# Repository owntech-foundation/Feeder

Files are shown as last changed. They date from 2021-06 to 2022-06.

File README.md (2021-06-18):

     * * * * * * * * * * * * * * * * * * * * * * * * * * * *
     *       _                                             *
     *    _ | | _                _______        _          *
     *   / || || \              |__   __|      | |         *
     *  / /`|_| \ \_        ___ __ | | ___  ___| |__       *
     * ( (`  ``  )\ \  /\  / | '_ \| |' _ `/ __| '_ `      *
     *  \ \ ___ / /\ \/  \/ /| |`| | | '__( (__| |`| |     *
     *   \_______/` \__/\__/`|_| |_|_ \___,\___|_| |_|     *
     *    ````````   ``` ```  ``  ```` ```` ``````  ``     *
     * D i g i t a l i z i n g  P o w e r  T o g e t h e r *
     * ``````````````````````````````````````````````````` *
     * * * * * * * * * * * * * * * * * * * * * * * * * * * *

# Low Side Synchronous Buck

This repository contains the design files relative to Low Side
Synchronous Buck Power converter. 

# License 

This project is under CERN-OHL-S open hardware Licence
Licence can be consulted inside of the Licence folder.

# Repository architecture 

The repository has the following organization 

* Datasheet 	Contains all the datasheet of main components and integrated circuits used in the design
* KiCAD_files	Contains the KiCAD project, for this converter two separated .pro files contains the two different pcb that compose the power converter. 
* libs  
   * footprints.pretty Contains the project specific footprints
      * footprints.3Dshapes contains the step files for project specific 3D footprints. 
* License 	Contains the pdf file of the CERN-OHL-S open hardware license
* Logo 		Contains the .png images of the logo used for title block
* Manufacturing_files
   * Definition_Package_Power Contains the definition package for manufacturing
   * Definition_Package_Shield Contains the definition package for manufacturing
* Software	Contains basic software for hardware tests.

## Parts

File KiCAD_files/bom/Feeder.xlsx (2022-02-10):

Prj: | Ultra wide input Feeder |  |  |  | Board Qty: | 100
Co.: |  |  |  |  | Unit Cost: | $0.00
Prj date: | mer. 09 févr. 2022 18:22:15 |  |  |  | Total Cost: | $0.00 |  |  |  | $0.00 | 0 |  |  |  | $0.00 | 0 |  |  |  | $0.00 | 0 |  |  |  | $0.00 | 0 |  |  |  | $0.00 | 0 |  |  |  | $0.00 | 0 |  |  |  | $0.00 | 0 |  |  |  | $0.00 | 0
$ date: | 2022-02-09 18:22:38
Global Part Info |  |  |  |  |  |  | Arrow |  |  |  |  | Digi-Key |  |  |  |  | Farnell |  |  |  |  | LCSC |  |  |  |  | Mouser |  |  |  |  | Newark |  |  |  |  | RS Components |  |  |  |  | TME
Refs | Value | Footprint | Manf# | Qty | Unit$ | Ext$ | Avail | Purch | Unit$ | Ext$ | Cat# | Avail | Purch | Unit$ | Ext$ | Cat# | Avail | Purch | Unit$ | Ext$ | Cat# | Avail | Purch | Unit$ | Ext$ | Cat# | Avail | Purch | Unit$ | Ext$ | Cat# | Avail | Purch | Unit$ | Ext$ | Cat# | Avail | Purch | Unit$ | Ext$ | Cat# | Avail | Purch | Unit$ | Ext$ | Cat#
C6 | 3.3uF, 400V | CP_Elec_10x10 | UUX2G3R3MNL1GS | 100 | $0.000 | $0.00 |  |  |  |  |  | 149 |  | $0.000 | $0.00 | 493-9988-1-ND (https://octopart.com/click/track?ai=8078&sig=0beef3b&sid=459&ppid=28166027&vpid=73754946&ct=offers) |  |  |  |  |  |  |  |  |  |  | 10 |  | $0.000 | $0.00 | 647UUX2G3R3MNL1GS (https://octopart.com/click/track?ai=8078&sig=02f3097&sid=2401&ppid=28166027&vpid=419389874&ct=offers) | NonStk |  | $0.000 | $0.00 | 44X4801 (https://octopart.com/click/track?c=1&ai=8078&sig=0e910e7&sid=2402&ppid=28166027&vpid=120922159&ct=offers) |  |  |  |  |  | NonStk |  | $0.000 | $0.00 | UUX2G3R3MNL1GS (https://octopart.com/click/track?ai=8078&sig=046e6c6&sid=1532&ppid=28166027&vpid=709108499&ct=offers)
C7 | 22nF | C_0805_2012Metric | CL21B223KBANNWC | 100 | $0.000 | $0.00 |  |  |  |  |  | 1 |  | $0.000 | $0.00 | 1276-2489-1-ND (https://octopart.com/click/track?ai=8078&sig=073ca1c&sid=459&ppid=24958179&vpid=72526342&ct=offers) |  |  |  |  |  |  |  |  |  |  | 192855 |  | $0.000 | $0.00 | 187CL21B223KBANNWC (https://octopart.com/click/track?ai=8078&sig=00f3e82&sid=2401&ppid=24958179&vpid=726965811&ct=offers)
C8 | 1nF | C_0805_2012Metric | CL21B102KBANNNC | 100 | $0.000 | $0.00 | 53 |  | $0.000 | $0.00 | CL21B102KBANNNC (https://octopart.com/click/track?ai=8078&sig=06aa4b8&sid=1106&ppid=9299369&vpid=486017912&ct=offers) | 246849 |  | $0.000 | $0.00 | 1276-1020-1-ND (https://octopart.com/click/track?ai=8078&sig=0799db1&sid=459&ppid=9299369&vpid=72525966&ct=offers) | 80000 |  | $0.000 | $0.00 | 3013466 (https://octopart.com/click/track?ai=8078&sig=03081e6&sid=11744&ppid=9299369&vpid=541618916&ct=offers) | 175000 |  | $0.000 | $0.00 | C51210 (https://octopart.com/click/track?ai=8078&sig=01941ba&sid=27971&ppid=9299369&vpid=478449047&ct=offers) | 61331 |  | $0.000 | $0.00 | 187CL21B102KBANNNC (https://octopart.com/click/track?ai=8078&sig=0e237f6&sid=2401&ppid=9299369&vpid=659501522&ct=offers) | 42677 |  | $0.000 | $0.00 | 82AC9409 (https://octopart.com/click/track?ai=8078&sig=00bb4d6&sid=2402&ppid=9299369&vpid=511545733&ct=offers) |  |  |  |  |  | 6300 |  | $0.000 | $0.00 | CL21B102KBANNNC (https://octopart.com/click/track?ai=8078&sig=0f7fd1f&sid=1532&ppid=9299369&vpid=709157390&ct=offers)
C9 | 2.2uF | C_0805_2012Metric | CGA4J3X7R1H225K125AE | 100 | $0.000 | $0.00 | 3 |  | $0.000 | $0.00 | CGA4J3X7R1H225K125AE (https://octopart.com/click/track?ai=8078&sig=04caa6a&sid=1106&ppid=48568697&vpid=473450299&ct=offers) | 186 |  | $0.000 | $0.00 | 445-172477-1-ND (https://octopart.com/click/track?ai=8078&sig=0cbb5a1&sid=459&ppid=48568697&vpid=156791176&ct=offers) | NonStk |  | $0.000 | $0.00 | 2547054 (https://octopart.com/click/track?c=1&ai=8078&sig=0b88586&sid=819&ppid=48568697&vpid=262384550&ct=offers) |  |  |  |  |  | 22112 |  | $0.000 | $0.00 | 810CGA4J3X7R1H225KE (https://octopart.com/click/track?ai=8078&sig=0e6e3df&sid=2401&ppid=48568697&vpid=179719319&ct=offers) | NonStk |  | $0.000 | $0.00 | 84Y5689 (https://octopart.com/click/track?c=1&ai=8078&sig=04670b1&sid=2402&ppid=48568697&vpid=263616676&ct=offers) | 49040 |  | $0.000 | $0.00 | 9155257 (https://octopart.com/click/track?ai=8078&sig=063517c&sid=10022&ppid=48568697&vpid=268634339&ct=offers)
C12 | X7T, 100nF | C_0805_2012Metric | C2012X7T2E104M125AA | 100 | $0.000 | $0.00 | 2011 |  | $0.000 | $0.00 | C2012X7T2E104M125AA (https://octopart.com/click/track?ai=8078&sig=0181695&sid=1106&ppid=28169232&vpid=475688280&ct=offers) | 27982 |  | $0.000 | $0.00 | 445-14563-1-ND (https://octopart.com/click/track?ai=8078&sig=0a0f4e8&sid=459&ppid=28169232&vpid=73766894&ct=offers) | NonStk |  | $0.000 | $0.00 | 2839009 (https://octopart.com/click/track?c=1&ai=8078&sig=0eac3cb&sid=819&ppid=28169232&vpid=489916687&ct=offers) |  |  |  |  |  | 7395 |  | $0.000 | $0.00 | 810C2012X7T2E104MAA (https://octopart.com/click/track?ai=8078&sig=0eae5db&sid=2401&ppid=28169232&vpid=165546343&ct=offers) | NonStk |  | $0.000 | $0.00 | 29X4838 (https://octopart.com/click/track?c=1&ai=8078&sig=0ee07f9&sid=2402&ppid=28169232&vpid=120992231&ct=offers)
C14,C15 | 6.8nF | C_0805_2012Metric | 0805B682K631CT | 200 | $0.000 | $0.00 |  |  |  |  |  | NonStk |  | $0.000 | $0.00 | 1292-0805B682K631CTTR-ND (https://octopart.com/click/track?c=1&ai=8078&sig=01f460f&sid=459&ppid=71780471&vpid=788565294&ct=offers) |  |  |  |  |  |  |  |  |  |  | 470 |  | $0.000 | $0.00 | 7910805B682K631CT (https://octopart.com/click/track?ai=8078&sig=02fc642&sid=2401&ppid=71780471&vpid=536603843&ct=offers)
C16 | 10uF | C_1210_3225Metric | UMK325C7106KM-T | 100 | $0.000 | $0.00 |  |  |  |  |  | NonStk |  | $0.000 | $0.00 | UMK325C7106KM-T-ND (https://octopart.com/click/track?c=1&ai=8078&sig=0264a5d&sid=459&ppid=7073241&vpid=137719881&ct=offers) |  |  |  |  |  |  |  |  |  |  | 181615 |  | $0.000 | $0.00 | 963UMK325C7106KMT (https://octopart.com/click/track?ai=8078&sig=00ab734&sid=2401&ppid=7073241&vpid=87845719&ct=offers) | NonStk |  | $0.000 | $0.00 | 09P7437 (https://octopart.com/click/track?c=1&ai=8078&sig=0140a20&sid=2402&ppid=7073241&vpid=96653055&ct=offers)
C17 | 100uF, 35V | CP_Elec_8x10 | EDH107M035A9MAA | 100 | $0.000 | $0.00 |  |  |  |  |  | NonStk |  | $0.000 | $0.00 | EDH107M035A9MAA-ND (https://octopart.com/click/track?c=1&ai=8078&sig=060caa0&sid=459&ppid=77807158&vpid=409529372&ct=offers) |  |  |  |  |  |  |  |  |  |  | 3550 |  | $0.000 | $0.00 | 80EDH107M035A9MAA (https://octopart.com/click/track?ai=8078&sig=0fc720f&sid=2401&ppid=77807158&vpid=458206257&ct=offers) | NonStk |  | $0.000 | $0.00 | 87AC4813 (https://octopart.com/click/track?c=1&ai=8078&sig=0d1a016&sid=2402&ppid=77807158&vpid=524242692&ct=offers)
C18 | C0G, 100pF | C_0805_2012Metric | CL21C101JBANNNC | 100 | $0.000 | $0.00 | 232000 |  | $0.000 | $0.00 | CL21C101JBANNNC (https://octopart.com/click/track?ai=8078&sig=042812e&sid=1106&ppid=9299371&vpid=486018360&ct=offers) | 50629 |  | $0.000 | $0.00 | 1276-1014-1-ND (https://octopart.com/click/track?ai=8078&sig=03ad40d&sid=459&ppid=9299371&vpid=72526845&ct=offers) | 3950 |  | $0.000 | $0.00 | 3013502 (https://octopart.com/click/track?ai=8078&sig=041580c&sid=819&ppid=9299371&vpid=629188470&ct=offers) | 601250 |  | $0.000 | $0.00 | C1790 (https://octopart.com/click/track?ai=8078&sig=05ecd53&sid=27971&ppid=9299371&vpid=478449053&ct=offers) | 55959 |  | $0.000 | $0.00 | 187CL21C101JBANNNC (https://octopart.com/click/track?ai=8078&sig=0e2e8f4&sid=2401&ppid=9299371&vpid=658751464&ct=offers) | NonStk |  | $0.000 | $0.00 | 82AC9471 (https://octopart.com/click/track?c=1&ai=8078&sig=08c5595&sid=2402&ppid=9299371&vpid=511545797&ct=offers) | 72000 |  | $0.000 | $0.00 | 7665875 (https://octopart.com/click/track?ai=8078&sig=02f6e75&sid=10022&ppid=9299371&vpid=209745986&ct=offers) | 107600 |  | $0.000 | $0.00 | CL21C101JBANNNC (https://octopart.com/click/track?ai=8078&sig=0da7126&sid=1532&ppid=9299371&vpid=709157463&ct=offers)
C19,C20 | 4.7uF | C_1210_3225Metric | DNP | 200 | $0.000 | $0.00
C21 | 680pF | C_1812_4532Metric | 302R29W681KV3E-****-SC | 100 | $0.000 | $0.00 |  |  |  |  |  | 7060 |  | $0.000 | $0.00 | 709-1093-1-ND (https://octopart.com/click/track?ai=8078&sig=078d3bc&sid=459&ppid=7978898&vpid=34203770&ct=offers) |  |  |  |  |  |  |  |  |  |  | 36692 |  | $0.000 | $0.00 | 605302R29W681KV3ESC (https://octopart.com/click/track?ai=8078&sig=094f0bc&sid=2401&ppid=7978898&vpid=81553806&ct=offers) | NonStk |  | $0.000 | $0.00 | 58M3253 (https://octopart.com/click/track?c=1&ai=8078&sig=0621320&sid=2402&ppid=7978898&vpid=12114671&ct=offers)
C22 | 10nF | C_0805_2012Metric | CL21B103KBANNND | 100 | $0.000 | $0.00 |  |  |  |  |  | NonStk |  | $0.000 | $0.00 | CL21B103KBANNND-ND (https://octopart.com/click/track?c=1&ai=8078&sig=07ec1f0&sid=459&ppid=19832252&vpid=72526020&ct=offers) |  |  |  |  |  |  |  |  |  |  | 28655 |  | $0.000 | $0.00 | 187CL21B103KBANNND (https://octopart.com/click/track?ai=8078&sig=099313b&sid=2401&ppid=19832252&vpid=726965796&ct=offers) |  |  |  |  |  |  |  |  |  |  | 10600 |  | $0.000 | $0.00 | CL21B103KBANNND (https://octopart.com/click/track?ai=8078&sig=0718426&sid=1532&ppid=19832252&vpid=709157396&ct=offers)
COMP1,CS1,GND1,GND2,GND3,GND4,MOSD1,MOSG1,MOSS1,TP1,TP6,VIN1,VOUT1,VOUT_GND1 | TestPoint | TestPoint_THTPad_D2.0mm_Drill1.0mm | DNP | 1400 | $0.000 | $0.00
D4 | MURA130T3G | D_SMA | MURA130T3G (https://www.mouser.fr/datasheet/2/308/1/MURA130T3_D-2316423.pdf) | 100 | $0.000 | $0.00 |  |  |  |  |  | NonStk |  | $0.000 | $0.00 | MURA130T3GOSCT-ND (https://octopart.com/click/track?c=1&ai=8078&sig=031c13b&sid=459&ppid=332346&vpid=51297157&ct=offers) | NonStk |  | $0.000 | $0.00 | 1651056 (https://octopart.com/click/track?c=1&ai=8078&sig=0a7f3ce&sid=819&ppid=332346&vpid=139248412&ct=offers) |  |  |  |  |  | 5000 |  | $0.000 | $0.00 | 863MURA130T3G (https://octopart.com/click/track?ai=8078&sig=0333514&sid=2401&ppid=332346&vpid=458432704&ct=offers) | 193 |  | $0.000 | $0.00 | 42K1578 (https://octopart.com/click/track?ai=8078&sig=07a66da&sid=2402&ppid=332346&vpid=2972890&ct=offers)
D5 | 9.1V | D_SOD-323 | MM3Z9V1T1G (https://www.mouser.fr/datasheet/2/308/1/MM3Z2V4T1_D-2316321.pdf) | 100 | $0.000 | $0.00 | 18 |  | $0.000 | $0.00 | MM3Z9V1T1G (https://octopart.com/click/track?ai=8078&sig=0d7b3bb&sid=1106&ppid=700692&vpid=473370526&ct=offers) | 2554 |  | $0.000 | $0.00 | MM3Z9V1T1GOSCT-ND (https://octopart.com/click/track?ai=8078&sig=00c2dd9&sid=459&ppid=700692&vpid=43967584&ct=offers) | 6795 |  | $0.000 | $0.00 | 1150496 (https://octopart.com/click/track?ai=8078&sig=09e01ec&sid=11744&ppid=700692&vpid=210226840&ct=offers) | 3707 |  | $0.000 | $0.00 | C603323 (https://octopart.com/click/track?ai=8078&sig=0c234f1&sid=27971&ppid=700692&vpid=752082712&ct=offers) | 17499 |  | $0.000 | $0.00 | 863MM3Z9V1T1G (https://octopart.com/click/track?ai=8078&sig=0883e79&sid=2401&ppid=700692&vpid=44862044&ct=offers) | 672 |  | $0.000 | $0.00 | 45J1637 (https://octopart.com/click/track?ai=8078&sig=0902ebf&sid=2402&ppid=700692&vpid=2977691&ct=offers) | NonStk |  | $0.000 | $0.00 | 8024653 (https://octopart.com/click/track?c=1&ai=8078&sig=0d07fa4&sid=10022&ppid=700692&vpid=199086310&ct=offers) | NonStk |  | $0.000 | $0.00 | MM3Z9V1T1G (https://octopart.com/click/track?ai=8078&sig=034a10e&sid=1532&ppid=700692&vpid=709121646&ct=offers)
D6 | STTH4R02U | D_SMB | BAS20HT1G | 100 | $0.000 | $0.00 | 1563 |  | $0.000 | $0.00 | BAS20HT1G (https://octopart.com/click/track?ai=8078&sig=038f86c&sid=1106&ppid=709429&vpid=473363759&ct=offers) | 1222 |  | $0.000 | $0.00 | BAS20HT1GOSCT-ND (https://octopart.com/click/track?ai=8078&sig=0e45b77&sid=459&ppid=709429&vpid=34059466&ct=offers) | 8200 |  | $0.000 | $0.00 | 2463444 (https://octopart.com/click/track?ai=8078&sig=0c13577&sid=819&ppid=709429&vpid=255436237&ct=offers) | 10520 |  | $0.000 | $0.00 | C152543 (https://octopart.com/click/track?ai=8078&sig=0ff7a5d&sid=27971&ppid=709429&vpid=476992952&ct=offers) | 15405 |  | $0.000 | $0.00 | 863BAS20HT1G (https://octopart.com/click/track?ai=8078&sig=0fa966a&sid=2401&ppid=709429&vpid=37598335&ct=offers) | 8200 |  | $0.000 | $0.00 | 80Y6660 (https://octopart.com/click/track?ai=8078&sig=02dbe19&sid=2402&ppid=709429&vpid=271850561&ct=offers) | NonStk |  | $0.000 | $0.00 | 7925498P (https://octopart.com/click/track?c=1&ai=8078&sig=0062a5b&sid=10022&ppid=709429&vpid=437535841&ct=offers) | 10 |  | $0.000 | $0.00 | BAS20HT1G (https://octopart.com/click/track?ai=8078&sig=0297028&sid=1532&ppid=709429&vpid=709118471&ct=offers)
D7,D8 | BAS20HT1G | D_SOD-323 | BAS20HT1G | 200 | $0.000 | $0.00 | 1563 |  | $0.000 | $0.00 | BAS20HT1G (https://octopart.com/click/track?ai=8078&sig=038f86c&sid=1106&ppid=709429&vpid=473363759&ct=offers) | 1222 |  | $0.000 | $0.00 | BAS20HT1GOSCT-ND (https://octopart.com/click/track?ai=8078&sig=0e45b77&sid=459&ppid=709429&vpid=34059466&ct=offers) | 8200 |  | $0.000 | $0.00 | 2463444 (https://octopart.com/click/track?ai=8078&sig=0c13577&sid=819&ppid=709429&vpid=255436237&ct=offers) | 10520 |  | $0.000 | $0.00 | C152543 (https://octopart.com/click/track?ai=8078&sig=0ff7a5d&sid=27971&ppid=709429&vpid=476992952&ct=offers) | 15405 |  | $0.000 | $0.00 | 863BAS20HT1G (https://octopart.com/click/track?ai=8078&sig=0fa966a&sid=2401&ppid=709429&vpid=37598335&ct=offers) | 8200 |  | $0.000 | $0.00 | 80Y6660 (https://octopart.com/click/track?ai=8078&sig=02dbe19&sid=2402&ppid=709429&vpid=271850561&ct=offers) | NonStk |  | $0.000 | $0.00 | 7925498P (https://octopart.com/click/track?c=1&ai=8078&sig=0062a5b&sid=10022&ppid=709429&vpid=437535841&ct=offers) | 10 |  | $0.000 | $0.00 | BAS20HT1G (https://octopart.com/click/track?ai=8078&sig=0297028&sid=1532&ppid=709429&vpid=709118471&ct=offers)
J1,J2,J3,J4 | Conn_01x01 | Pad_terminal | DNP | 400 | $0.000 | $0.00
NTC1 | 100k | R_0805_2012Metric | ABNTC-0805-104J-4250F-T (https://www.mouser.fr/datasheet/2/3/ABNTC-0805-253593.pdf) | 100 | $0.000 | $0.00 |  |  |  |  |  | NonStk |  | $0.000 | $0.00 | 535-12856-2-ND (https://octopart.com/click/track?c=1&ai=8078&sig=0d1f3fb&sid=459&ppid=29811146&vpid=194407652&ct=offers) |  |  |  |  |  |  |  |  |  |  | 4044 |  | $0.000 | $0.00 | 815NTC805104J4250FT (https://octopart.com/click/track?ai=8078&sig=090dfaa&sid=2401&ppid=29811146&vpid=430900897&ct=offers) | NonStk |  | $0.000 | $0.00 | 96W7698 (https://octopart.com/click/track?c=1&ai=8078&sig=0b85f5f&sid=2402&ppid=29811146&vpid=95831388&ct=offers)
Q1#1 | TK13P25D,RQ - p1/2 | TO-252-2 | TK13P25D (https://www.mouser.fr/datasheet/2/408/TK13P25D_datasheet_en_20140106-1649876.pdf) | 100 | $0.000 | $0.00
Q1#2 | TK13P25D,RQ - p2/2 | TO-252-2 | RQ (https://www.mouser.fr/datasheet/2/408/TK13P25D_datasheet_en_20140106-1649876.pdf) | 100 | $0.000 | $0.00
R4 | 27k | R_0805_2012Metric | KTR10EZPF2702 | 100 | $0.000 | $0.00 |  |  |  |  |  | 5700 |  | $0.000 | $0.00 | RHM27KAHCT-ND (https://octopart.com/click/track?ai=8078&sig=0782fd9&sid=459&ppid=29236867&vpid=76922610&ct=offers) | 2318 |  | $0.000 | $0.00 | 2919074 (https://octopart.com/click/track?ai=8078&sig=0dab3f0&sid=819&ppid=29236867&vpid=521278501&ct=offers) |  |  |  |  |  | 5470 |  | $0.000 | $0.00 | 755KTR10EZPF2702 (https://octopart.com/click/track?ai=8078&sig=06582ee&sid=2401&ppid=29236867&vpid=447856352&ct=offers) | 2318 |  | $0.000 | $0.00 | 72AC5922 (https://octopart.com/click/track?ai=8078&sig=02426fc&sid=2402&ppid=29236867&vpid=509970016&ct=offers)
R5 | 100k | R_0805_2012Metric | KTR10EZPJ104 | 100 | $0.000 | $0.00 |  |  |  |  |  | NonStk |  | $0.000 | $0.00 | RHM100KBCT-ND (https://octopart.com/click/track?c=1&ai=8078&sig=0b4118a&sid=459&ppid=19170044&vpid=34225415&ct=offers) |  |  |  |  |  |  |  |  |  |  | 15665 |  | $0.000 | $0.00 | 755KTR10EZPJ104 (https://octopart.com/click/track?ai=8078&sig=0a01465&sid=2401&ppid=19170044&vpid=465335302&ct=offers)
R6 | 348K | R_0805_2012Metric | CR0805-FX-3483ELF | 100 | $0.000 | $0.00 |  |  |  |  |  | NonStk |  | $0.000 | $0.00 | CR0805-FX-3483ELF-ND (https://octopart.com/click/track?c=1&ai=8078&sig=0537185&sid=459&ppid=6075373&vpid=63620518&ct=offers) |  |  |  |  |  |  |  |  |  |  | 23062 |  | $0.000 | $0.00 | 652CR0805FX3483ELF (https://octopart.com/click/track?ai=8078&sig=0704b8e&sid=2401&ppid=6075373&vpid=99580320&ct=offers) | NonStk |  | $0.000 | $0.00 | 32K3076 (https://octopart.com/click/track?c=1&ai=8078&sig=0a04ef9&sid=2402&ppid=6075373&vpid=518541576&ct=offers)
R7 | 470 | R_0805_2012Metric | RC0805JR-07470RP | 100 | $0.000 | $0.00 | 4925 |  | $0.000 | $0.00 | RC0805JR07470RP (https://octopart.com/click/track?ai=8078&sig=01aeefa&sid=1106&ppid=47616104&vpid=473551910&ct=offers) | NonStk |  | $0.000 | $0.00 | YAG1333CT-ND (https://octopart.com/click/track?c=1&ai=8078&sig=0e8cd12&sid=459&ppid=47616104&vpid=131496801&ct=offers) |  |  |  |  |  |  |  |  |  |  | 8025 |  | $0.000 | $0.00 | 603RC0805JR07470RP (https://octopart.com/click/track?ai=8078&sig=00ebd60&sid=2401&ppid=47616104&vpid=474033905&ct=offers)
R8 | 348k | R_0805_2012Metric | CR0805-FX-3483ELF | 100 | $0.000 | $0.00 |  |  |  |  |  | NonStk |  | $0.000 | $0.00 | CR0805-FX-3483ELF-ND (https://octopart.com/click/track?c=1&ai=8078&sig=0537185&sid=459&ppid=6075373&vpid=63620518&ct=offers) |  |  |  |  |  |  |  |  |  |  | 23062 |  | $0.000 | $0.00 | 652CR0805FX3483ELF (https://octopart.com/click/track?ai=8078&sig=0704b8e&sid=2401&ppid=6075373&vpid=99580320&ct=offers) | NonStk |  | $0.000 | $0.00 | 32K3076 (https://octopart.com/click/track?c=1&ai=8078&sig=0a04ef9&sid=2402&ppid=6075373&vpid=518541576&ct=offers)
R9 | 240m | R_1210_3225Metric | RCWE1210R240FKEA (https://www.vishay.com/docs/20019/rcwe.pdf) | 100 | $0.000 | $0.00 | 5000 |  | $0.000 | $0.00 | RCWE1210R240FKEA (https://octopart.com/click/track?ai=8078&sig=02fe887&sid=1106&ppid=44349166&vpid=473534196&ct=offers) | 4095 |  | $0.000 | $0.00 | RCWE.24FCT-ND (https://octopart.com/click/track?ai=8078&sig=02c04b0&sid=459&ppid=44349166&vpid=115679007&ct=offers) | 8940 |  | $0.000 | $0.00 | 3784839 (https://octopart.com/click/track?ai=8078&sig=0f94c69&sid=819&ppid=44349166&vpid=751268921&ct=offers) |  |  |  |  |  | 8580 |  | $0.000 | $0.00 | 71RCWE1210R240FKEA (https://octopart.com/click/track?ai=8078&sig=0dc2e7b&sid=2401&ppid=44349166&vpid=117597675&ct=offers) | 1234 |  | $0.000 | $0.00 | 08AJ1694 (https://octopart.com/click/track?ai=8078&sig=0c66e4e&sid=2402&ppid=44349166&vpid=671740672&ct=offers)
R11 | 1.4K | R_0805_2012Metric | RC0805FR-071K4L | 100 | $0.000 | $0.00 | 1832 |  | $0.000 | $0.00 | RC0805FR071K4L (https://octopart.com/click/track?ai=8078&sig=0a345cd&sid=1106&ppid=1180832&vpid=473551161&ct=offers) | 214995 |  | $0.000 | $0.00 | 311-1.40KCRCT-ND (https://octopart.com/click/track?ai=8078&sig=032b5f7&sid=459&ppid=1180832&vpid=1749369&ct=offers) | 13710 |  | $0.000 | $0.00 | 3495993 (https://octopart.com/click/track?ai=8078&sig=0a9328e&sid=819&ppid=1180832&vpid=653863687&ct=offers) |  |  |  |  |  | 22207 |  | $0.000 | $0.00 | 603RC0805FR071K4L (https://octopart.com/click/track?ai=8078&sig=0efb0e9&sid=2401&ppid=1180832&vpid=56304300&ct=offers) | 12880 |  | $0.000 | $0.00 | 82AH8275 (https://octopart.com/click/track?ai=8078&sig=09af2c5&sid=2402&ppid=1180832&vpid=655850498&ct=offers) |  |  |  |  |  | 790 |  | $0.000 | $0.00 | RC0805FR071K4L (https://octopart.com/click/track?ai=8078&sig=00e9036&sid=1532&ppid=1180832&vpid=709258348&ct=offers)
R12,R15,R18 | 10k | R_0805_2012Metric | CRT0805-FZ-1002ELF | 300 | $0.000 | $0.00 | 8275 |  | $0.000 | $0.00 | CRT0805FZ1002ELF (https://octopart.com/click/track?ai=8078&sig=0c026f5&sid=1106&ppid=10484700&vpid=473160273&ct=offers) | 4000 |  | $0.000 | $0.00 | CRT0805-FZ-1002ELFCT-ND (https://octopart.com/click/track?ai=8078&sig=099df1e&sid=459&ppid=10484700&vpid=61158602&ct=offers) | 21 |  | $0.000 | $0.00 | 2008317 (https://octopart.com/click/track?ai=8078&sig=0084ca8&sid=819&ppid=10484700&vpid=138672063&ct=offers) |  |  |  |  |  | 18412 |  | $0.000 | $0.00 | 652CRT0805FZ1002ELF (https://octopart.com/click/track?ai=8078&sig=09f5997&sid=2401&ppid=10484700&vpid=37741697&ct=offers) | 11 |  | $0.000 | $0.00 | 41Y1375 (https://octopart.com/click/track?ai=8078&sig=0f9fbcb&sid=2402&ppid=10484700&vpid=250198205&ct=offers) | 3350 |  | $0.000 | $0.00 | 7409224 (https://octopart.com/click/track?ai=8078&sig=00c13b9&sid=10022&ppid=10484700&vpid=198997719&ct=offers)
R13,R17,R20 | 10 | R_0805_2012Metric | CRCW080510R0JNEAC | 300 | $0.000 | $0.00 | 49 |  | $0.000 | $0.00 | CRCW080510R0JNEAC (https://octopart.com/click/track?ai=8078&sig=0221b64&sid=1106&ppid=23798538&vpid=480974327&ct=offers) | 69322 |  | $0.000 | $0.00 | 541-4167-1-ND (https://octopart.com/click/track?ai=8078&sig=013f719&sid=459&ppid=23798538&vpid=454353720&ct=offers) |  |  |  |  |  |  |  |  |  |  | 138976 |  | $0.000 | $0.00 | 71CRCW080510R0JNEAC (https://octopart.com/click/track?ai=8078&sig=00f8257&sid=2401&ppid=23798538&vpid=458953946&ct=offers) | NonStk |  | $0.000 | $0.00 | 98AC1024 (https://octopart.com/click/track?c=1&ai=8078&sig=0bf89aa&sid=2402&ppid=23798538&vpid=634340864&ct=offers)
R14 | 38.3k | R_0805_2012Metric | CRCW080538K3FKEA | 100 | $0.000 | $0.00 |  |  |  |  |  | 722 |  | $0.000 | $0.00 | 541-38.3KCCT-ND (https://octopart.com/click/track?ai=8078&sig=04292f8&sid=459&ppid=39854820&vpid=114978957&ct=offers) | 9755 |  | $0.000 | $0.00 | 1652988 (https://octopart.com/click/track?ai=8078&sig=06e7e1d&sid=11744&ppid=39854820&vpid=249315642&ct=offers) |  |  |  |  |  | 686 |  | $0.000 | $0.00 | 71CRCW080538.3KE3 (https://octopart.com/click/track?ai=8078&sig=05a8f9c&sid=2401&ppid=39854820&vpid=115160585&ct=offers) | 2610 |  | $0.000 | $0.00 | 53K0193 (https://octopart.com/click/track?ai=8078&sig=0e72440&sid=2402&ppid=39854820&vpid=115416899&ct=offers)
R16 | 2.2 | R_0805_2012Metric | RK73B2ATTDD2R2J | 100 | $0.000 | $0.00 |  |  |  |  |  |  |  |  |  |  |  |  |  |  |  |  |  |  |  |  | 20432 |  | $0.000 | $0.00 | 660RK73B2ATTDD2R2J (https://octopart.com/click/track?ai=8078&sig=0fe4351&sid=2401&ppid=57087488&vpid=193859280&ct=offers)
T1 | PA2467NL | PA2467NL | PA2467NL (https://productfinder.pulseelectronics.com/api/open/product-attachments/datasheet/pa2467nlt) | 100 | $0.000 | $0.00 | 750 |  | $0.000 | $0.00 | PA2467NL (https://octopart.com/click/track?ai=8078&sig=03cddbf&sid=1106&ppid=18290109&vpid=473412033&ct=offers) | NonStk |  | $0.000 | $0.00 | 553-3321-ND (https://octopart.com/click/track?c=1&ai=8078&sig=0015381&sid=459&ppid=18290109&vpid=253365440&ct=offers) |  |  |  |  |  |  |  |  |  |  | 2751 |  | $0.000 | $0.00 | 673PA2467NL (https://octopart.com/click/track?ai=8078&sig=0bea9f7&sid=2401&ppid=18290109&vpid=275699093&ct=offers)
U2 | NCP12700 | MSOP-10_3x3mm_P0.5mm | NCP12700ADNR2G (https://www.onsemi.com/pdf/datasheet/ncp12700-d.pdf) | 100 | $0.000 | $0.00 | 2609 |  | $0.000 | $0.00 | NCP12700ADNR2G (https://octopart.com/click/track?ai=8078&sig=0ba64aa&sid=1106&ppid=89706344&vpid=707207381&ct=offers) | 3797 |  | $0.000 | $0.00 | 1990-NCP12700ADNR2GCT-ND (https://octopart.com/click/track?c=1&ai=8078&sig=009cb1c&sid=459&ppid=89706344&vpid=763727272&ct=offers) | 3969 |  | $0.000 | $0.00 | 2895693 (https://octopart.com/click/track?ai=8078&sig=0a2215c&sid=819&ppid=89706344&vpid=492584107&ct=offers) |  |  |  |  |  | 1355 |  | $0.000 | $0.00 | 863NCP12700ADNR2G (https://octopart.com/click/track?ai=8078&sig=0eba9ca&sid=2401&ppid=89706344&vpid=481500564&ct=offers) | 3969 |  | $0.000 | $0.00 | 62AC7304 (https://octopart.com/click/track?ai=8078&sig=01dd9ed&sid=2402&ppid=89706344&vpid=492708771&ct=offers)
U3 | HMHA2801A | SO-4_4.4x2.3mm_P1.27mm | HMHA2801A (https://www.mouser.fr/datasheet/2/308/1/HMHA2801B_D-2314371.pdf) | 100 | $0.000 | $0.00 |  |  |  |  |  | NonStk |  | $0.000 | $0.00 | HMHA2801A-ND (https://octopart.com/click/track?c=1&ai=8078&sig=078b50c&sid=459&ppid=84329105&vpid=452468346&ct=offers) | 2957 |  | $0.000 | $0.00 | 2453212 (https://octopart.com/click/track?ai=8078&sig=0a90ccc&sid=819&ppid=84329105&vpid=440254787&ct=offers) |  |  |  |  |  | 462 |  | $0.000 | $0.00 | 512HMHA2801A (https://octopart.com/click/track?ai=8078&sig=01f73a8&sid=2401&ppid=84329105&vpid=438584723&ct=offers) | 2158 |  | $0.000 | $0.00 | 31Y2002 (https://octopart.com/click/track?ai=8078&sig=0d5bd16&sid=2402&ppid=84329105&vpid=439870991&ct=offers) |  |  |  |  |  | 3 |  | $0.000 | $0.00 | HMHA2801A (https://octopart.com/click/track?ai=8078&sig=0462abe&sid=1532&ppid=84329105&vpid=763734031&ct=offers)
U4#1 | TL431MFDT,215 - p1/2 | SOT-23 | TL431MFDT (https://www.mouser.fr/datasheet/2/916/TL431_FAM-1600378.pdf) | 100 | $0.000 | $0.00 |  |  |  |  |  |  |  |  |  |  | NonStk |  | $0.000 | $0.00 | 2095481 (https://octopart.com/click/track?c=1&ai=8078&sig=0b0ff44&sid=819&ppid=79112777&vpid=414866965&ct=offers)
U4#2 | TL431MFDT,215 - p2/2 | SOT-23 | 215 (https://www.mouser.fr/datasheet/2/916/TL431_FAM-1600378.pdf) | 100 | $0.000 | $0.00 |  |  |  |  |  | 58 |  | $0.000 | $0.00 | 215PV-ND (https://octopart.com/click/track?ai=8078&sig=0797dd1&sid=459&ppid=89173600&vpid=462080608&ct=offers) | 2 |  | $0.000 | $0.00 | 2903716 (https://octopart.com/click/track?ai=8078&sig=004342a&sid=819&ppid=89173600&vpid=490808707&ct=offers) |  |  |  |  |  |  |  |  |  |  | 2 |  | $0.000 | $0.00 | 62AC1312 (https://octopart.com/click/track?ai=8078&sig=0daa01e&sid=2402&ppid=89173600&vpid=492148436&ct=offers)
 | Used currency rates: |  |  |  | Total Purchase: | $0.00 | Buy here (https://www.arrow.com/en/bom-tool/) |  |  | $0.00 |  | Buy here (https://www.digikey.com/ordering/shoppingcart) |  |  | $0.00 |  | Buy here (https://fr.farnell.com/en-FR/quick-order?isQuickPaste=true) |  |  | $0.00 |  | Buy here (https://lcsc.com/bom.html) |  |  | $0.00 |  | Buy here (https://mouser.com/bom/) |  |  | $0.00 |  | Buy here (https://www.newark.com/quick-order?isQuickPaste=true) |  |  | $0.00 |  | Buy here (https://uk.rs-online.com/web/mylists/manualQuotes.html?method=showEnquiryCreationPage&mode=new) |  |  | $0.00 |  | Buy here (https://www.tme.eu/en/Profile/QuickBuy/load.html) |  |  | $0.00
 | USD($)/GBP(£): | 1.357189484 |  |  | Purchase description: |  |  |  |  |  |  |  |  |  |  |  |  |  |  |  |  |  | Copy this header and order to a CSV file and use it for JLCPCB manufacturer PCB house. The multipart components that use "#" symbol are not allowed by JLCPCB.
KiCost® v1.1.5

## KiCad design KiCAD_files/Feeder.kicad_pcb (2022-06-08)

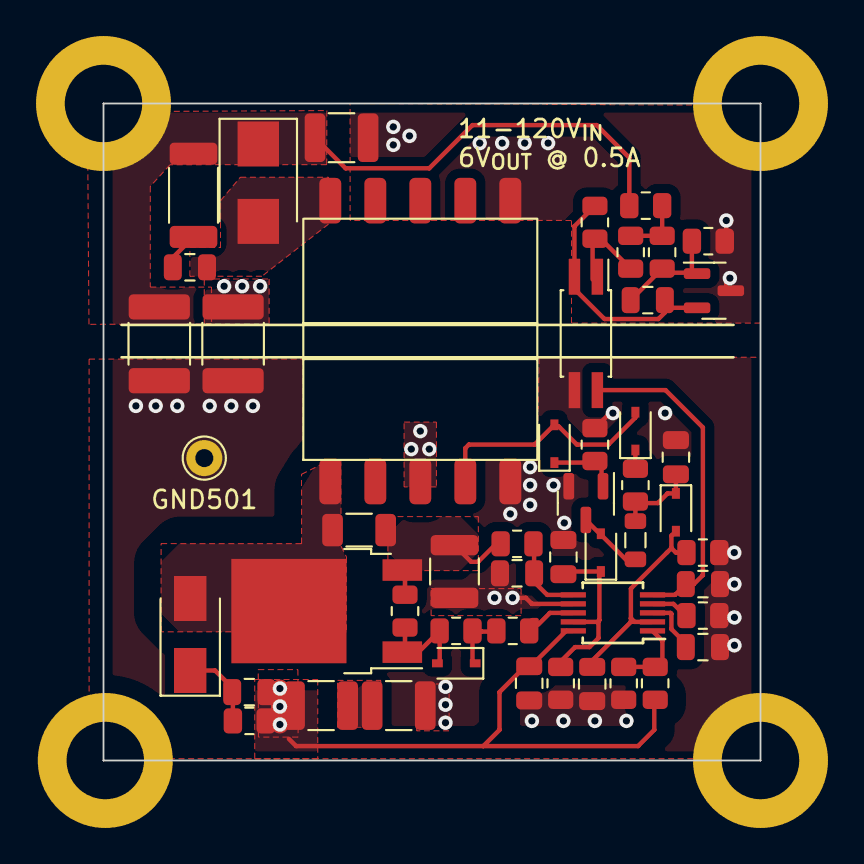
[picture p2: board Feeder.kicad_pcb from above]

Board: 4 copper layers, 36.5 x 36.5 mm, 54 parts (0 on the bottom side), 29 nets.

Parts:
C501, C502: 4.7uF; C_1210_3225Metric
C503: 10nF; C_0805_2012Metric
C504: 22nF; C_0805_2012Metric
C505: 1nF; C_0805_2012Metric
C506: C0G, 100pF; C_0805_2012Metric
C507, C509: 1uF; C_0805_2012Metric
C508: X7T, 100nF; C_0805_2012Metric
C510, C516: 6.8nF; C_0805_2012Metric
C511: 100pF 1kV DNP; C_1206_3216Metric
C512, C513: 2.2nF; C_1812_4532Metric
C514: 1nF 500V DNP; C_0805_2012Metric
C515: 10uF; C_1210_3225Metric
D501: 6.2V; D_SOD-323
D502, D503, D505, D506: BAS20HT1G; D_SOD-323
D504: MURA130T3G; D_SMA
D507: STTH4R02U; D_SMB
GND501: GND; TestPoint_THTPad_D2.0mm_Drill1.0mm
J501, J502, J503, J504: Conn_01x01; MountingHole_4.3mm_M4_DIN965_Pad
L501: 100uH; L_0805_2012Metric
NTC501: 100k; R_0805_2012Metric
Q501: 60V N channel; SOT-23
Q502: TK13P25D,RQ; TO-252-2
R501: 348K; R_0805_2012Metric
R502, R518: 27k; R_0805_2012Metric
R503: 100k; R_0805_2012Metric
R504, R512, R514: 1.4K; R_0805_2012Metric
R505: 2.2; R_0805_2012Metric
R506: 470; R_0805_2012Metric
R507, R511, R516: 10; R_0805_2012Metric
R508, R515: 10k; R_0805_2012Metric
R509: 348k; R_0805_2012Metric
R510: 240m; R_1210_3225Metric
R513: 10R 1W DNP; R_2010_5025Metric
R517: 38.3k; R_0805_2012Metric
T501: PA2467NL
U501: NCP12700; MSOP-10_3x3mm_P0.5mm
U502: HMHA2801A; SO-4_4.4x2.3mm_P1.27mm
U503: TL431MFDT,215; SOT-23

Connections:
/VIN: C501.1, C508.1, C510.1, J501.1, R501.1, R509.2, T501.3, U501.10 (VIN)
/VOUT: C513.2, C515.1, D507.1 (K), J503.1, R513.2, R516.1
DGND: C512.2, C515.2, J504.1, R518.2, T501.10, U503.3 (A)
GND: C502.2, C503.1, C504.2, C505.2, C506.2, C507.2, C508.2, C509.2, C512.1, C513.1, GND501.1, J502.1, NTC501.2, Q501.2 (S), R502.2, R503.2, R504.2, R510.2, R512.2, T501.1, U501.7 (GND), U502.3
HV: C501.2, C502.1
MOSD: C511.1, D504.2 (A), Q502.2 (D), T501.5
MOSS: C511.2, Q502.3 (S), R506.2, R508.1, R510.1
unnamed: C503.2, D501.2 (A), NTC501.1, U501.2 (FLT)
unnamed: C504.1, U501.3 (SS)
unnamed: C505.1, U501.5 (COMP), U502.4
unnamed: C506.1, R506.1, U501.6 (CS)
unnamed: C510.2, D504.1 (K), R509.1
unnamed: C514.1, D507.2 (A), T501.6
unnamed: C514.2, R513.1
unnamed: C516.1, R515.2, U502.2, U503.2 (K)
unnamed: C516.2, R517.2, R518.1, U503.1 (REF)
unnamed: D502.2 (A), L501.1, Q501.3 (D)
unnamed: D503.1 (K), R505.2, R507.1
unnamed: D503.2 (A), Q502.1 (G), R507.2, R508.2
unnamed: D505.1 (K), R511.2
unnamed: D505.2 (A), D506.2 (A), T501.2
unnamed: D506.1 (K), Q501.1 (G), R512.1
unnamed: R501.2, R502.1, U501.1 (UVLO)
unnamed: R503.1, U501.4 (RT)
unnamed: R505.1, U501.8 (DRV)
unnamed: R514.1, R516.2, R517.1
unnamed: R514.2, R515.1, U502.1
VAUX: C509.1, D501.1 (K), L501.2, R511.1
VBoost: C507.1, D502.1 (K), R504.1, U501.9 (VCC)

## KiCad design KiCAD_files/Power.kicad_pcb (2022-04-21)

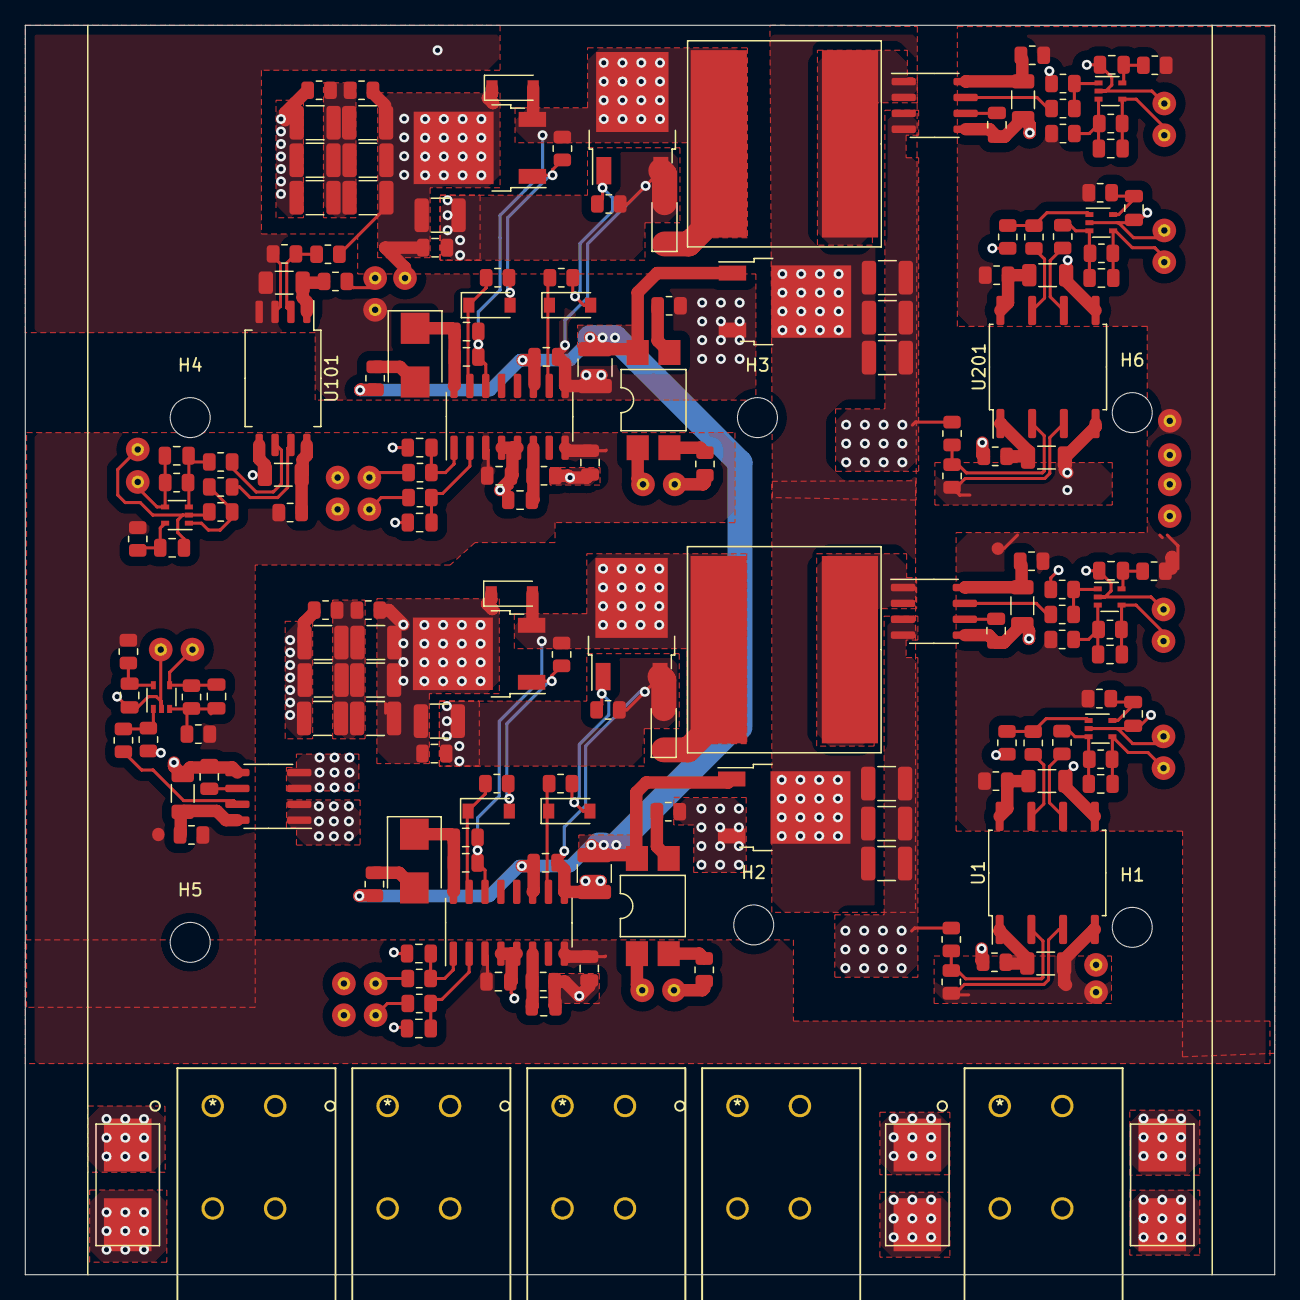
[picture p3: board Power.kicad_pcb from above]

Board: 4 copper layers, 100.0 x 100.0 mm, 215 parts (0 on the bottom side), 97 nets.

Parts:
C1, C11, C12, C101, C102, C120, C201, C211, C212: 100nF; C_1206_3216Metric
C2, C4, C10, C14, C15, C17, C20, C21, C104, C119, C202, C204, C210, C214, C215, C217, C220, C221: 100nF; C_0805_2012Metric
C3, C5, C8, C105, C106, C107, C108, C109, C110, C111, C112, C113, C114, C115, C116, C203, C205, C208: 4.7uF; C_1210_3225Metric
C6, C7, C206, C207: 33pF; C_0805_2012Metric
C9, C118, C209: 1nF; C_0805_2012Metric
C13, C19, C103, C117, C213, C219: 20pF; C_0805_2012Metric
C16, C216: 10uF; C_1210_3225Metric
C18, C218: 1uF; C_0805_2012Metric
C23, C223: 100nF; C_1210_3225Metric
D1, D201: STTH4R02U; D_SMB
D2, D3, D202, D203: STPS0520Z; D_SOD-123
D_L1, D_L3, D_L201, D_L202: STTH1002CB; D_SOD-123
F101, F102, F103: 8A; Fuse_holder_omni_blok
H1, H2, H3, H4, H5, H6: MountingHole; MountingHole_3.2mm_M3
HS101: Heatsink_Pad; custom_heatsink
J1, J2, J3, J4, J5, J6, J7, J8, J9, J10, J104, J105, J106, J107, J108, J109, J110, J111, J112, J113, J114, J115, J116, J201, J202, J203, J204, J205, J206, J207, J208, J209, J210: Conn_01x01; 0906_millmax
J101, J102, J103, J117, J118: 2604-1102; WAGO-2604-1102
L1, L201: 33uH; SRP1510CA-330M
Q1, Q2, Q3, Q201, Q202, Q203: IPD200N15N3; TO-252-2
R1, R2, R19, R201, R202, R219: 51; R_0805_2012Metric
R3, R17, R18, R107, R108, R203, R217, R218: 20k; R_0805_2012Metric
R4, R5, R101, R102, R204, R205: 27k; R_0805_2012Metric
R6, R8, R103, R104, R206, R208: 12k; R_0805_2012Metric
R7, R207: 2.2; R_0805_2012Metric
R9, R14, R15, R21, R22, R23, R24, R25, R26, R27, R28, R29, R30, R31, R105, R110, R209, R214, R215, R221, R222: 1k; R_0805_2012Metric
R10, R11, R210, R211: 2,2; R_0805_2012Metric
R16, R20, R106, R109, R216, R220: 5.9k; R_0805_2012Metric
Rbleed1, Rbleed2, Rbleed101, Rbleed102: 1M; R_0805_2012Metric
Rv1, Rv201: 150K; R_0805_2012Metric
Rv2, Rv202: 470; R_0805_2012Metric
Rv101: 330K; R_0805_2012Metric
Rv102: 5.6K; R_0805_2012Metric
U1, U201: AMC1100DUB; SOP-8_6.62x9.15mm_P2.54mm
U2, U202: ACS730xLCTR-20AB; SOIC-8_3.9x4.9mm_P1.27mm
U3, U203: UCC21222DR; SOIC-16_3.9x9.9mm_P1.27mm
U4, U5, U102, U103, U204, U205: OPA316; SOT-353_SC-70-5
U6, U206: SFH617A-2X009T; SMDIP-4_W7.62mm
U101: AMC1311; SOIC-8_7.5x5.85mm_P1.27mm
U104: +-20A; SOIC-8_3.9x4.9mm_P1.27mm

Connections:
+5P: J104.1, R29.1
+5V: J109.1, R30.1, R31.1
+5VD: C2.1, C4.1, C202.1, C204.1, J107.1, R9.1, R17.1, R21.1, R23.1, R24.1, R25.1, R26.2, R27.1, R28.2, R105.1, R107.1, R110.1, R209.1, R217.1, R221.1, U3.3 (VCCI), U3.8 (VCCI), U203.3 (VCCI), U203.8 (VCCI)
+12V: C14.1, C16.1, C214.1, C216.1, Q3.1 (G), Q203.1 (G), R7.2, R207.2, U3.11 (VDDB), U6.4, U203.11 (VDDB), U206.4
/IIHigh: R106.1, U104.7 (VIOUT)
/IIHigh_op: C117.2, J115.1, R109.2, U103.4
/Power Leg 1/HRTIM1_CH1: J201.1, R201.1
/Power Leg 1/HRTIM1_CH2: J202.1, R202.1
/Power Leg 1/IILow: R216.1, U202.7 (VIOUT)
/Power Leg 1/IILow1_op: C219.2, J209.1, R220.2, U205.4
/Power Leg 1/N_GND: J207.1, U206.1
/Power Leg 1/PWM_H1: D202.1 (K), R210.1, U203.15 (OUTA)
/Power Leg 1/PWM_L1: D203.1 (K), R211.1, U203.10 (OUTB)
/Power Leg 1/SW_Node: C215.2, C218.2, D_L201.1 (K), D_L202.2 (A), L201.2, Q201.3 (S), Q202.2 (D), R214.1, U203.14 (VSSA)
/Power Leg 1/VILow+: Rv201.2, Rv202.1, U201.2 (VINP)
/Power Leg 1/VILow_op: C213.2, J205.1, R208.2, U204.4
/Power Leg 2/HRTIM1_CH1: J1.1, R1.1
/Power Leg 2/HRTIM1_CH2: J2.1, R2.1
/Power Leg 2/IILow: R16.1, U2.7 (VIOUT)
/Power Leg 2/IILow1_op: C19.2, J9.1, R20.2, U5.4
/Power Leg 2/N_GND: J7.1, U6.1
/Power Leg 2/PWM_H1: D2.1 (K), R10.1, U3.15 (OUTA)
/Power Leg 2/PWM_L1: D3.1 (K), R11.1, U3.10 (OUTB)
/Power Leg 2/SW_Node: C15.2, C18.2, D_L1.1 (K), D_L3.2 (A), L1.2, Q1.3 (S), Q2.2 (D), R14.1, U3.14 (VSSA)
/Power Leg 2/VILow+: Rv1.2, Rv2.1, U1.2 (VINP)
/Power Leg 2/VILow_op: C13.2, J5.1, R8.2, U4.4
/V1_Low: C203.1, C205.1, C208.1, F102.1, Rv201.1, U202.3 (IP-), U202.4 (IP-)
/V2_Low: C3.1, C5.1, C8.1, F101.1, Rv1.1, U2.3 (IP-), U2.4 (IP-)
/VIHigh+: Rv101.2, Rv102.1, U101.2 (VIN)
/VIHigh_op: C103.2, J111.1, R104.2, U102.4
/VI_High: F103.1, J118.1, J118.2, J118.3, J118.4
/V_High: C21.1, C23.1, C105.1, C107.1, C109.1, C111.1, C113.1, C115.1, C221.1, C223.1, D_L3.1 (K), D_L202.1 (K), J113.1, Q1.2 (D), Q201.2 (D), Rbleed1.1, Rbleed101.1, Rv101.1, U104.3 (IP-), U104.4 (IP-)
DGND: C2.2, C4.2, C6.1, C7.2, C9.1, C10.2, C11.2, C12.1, C17.2, C20.2, C102.2, C104.2, C118.1, C119.2, C120.1, C202.2, C204.2, C206.1, C207.2, C209.1, C210.2, C211.2, C212.1, C217.2, C220.2, J3.1, J4.1, J6.1, J8.1, J10.1, J106.1, J108.1, J112.1, J116.1, J203.1, J204.1, J206.1, J208.1, J210.1, R3.1, R18.2, R19.1, R103.1, R108.2, R203.1, R218.2, R219.1, U1.5 (GND2), U2.5 (GND), U3.4 (GND), U3.5 (DIS), U4.2 (V-), U5.2 (V-), U101.5 (GND2), U102.2 (V-), U103.2 (V-), U104.5 (GND), U201.5 (GND2), U202.5 (GND), U203.4 (GND), U203.5 (DIS), U204.2 (V-), U205.2 (V-)
GNDREF: C14.2, C16.2, C21.2, C23.2, C101.2, C106.2, C108.2, C110.2, C112.2, C114.2, C116.2, C214.2, C216.2, C221.2, C223.2, D_L1.2 (A), D_L201.2 (A), J114.1, J117.1, J117.2, J117.3, J117.4, Q2.3 (S), Q3.3 (S), Q202.3 (S), Q203.3 (S), R15.1, R22.1, R215.1, R222.1, Rbleed2.2, Rbleed102.2, Rv102.2, U3.9 (VSSB), U101.3 (SHTDN), U101.4 (GND1), U203.9 (VSSB)
NGND: C1.2, C3.2, C5.2, C8.2, C201.2, C203.2, C205.2, C208.2, J103.1, J103.2, J103.3, J103.4, J110.1, Q3.2 (D), Q203.2 (D), Rv2.2, Rv202.2, U1.3 (VINN), U1.4 (GND1), U201.3 (VINN), U201.4 (GND1)
unnamed: C1.1, R31.2, U1.1 (VDD1)
unnamed: C6.2, R1.2, U3.1 (INA)
unnamed: C7.1, R2.2, U3.2 (INB)
unnamed: C9.2, U2.6 (VZCR)
unnamed: C10.1, R3.2, U3.6 (DT)
unnamed: C11.1, R27.2, U1.8 (VDD2)
unnamed: C12.2, R28.1, U2.8 (VCC)
unnamed: C13.1, R5.2, R8.1, U4.3 (-)
unnamed: C15.1, C18.1, D1.1 (K), U3.16 (VDDA)
unnamed: C17.1, R9.2, U4.5 (V+)
unnamed: C19.1, R17.2, R20.1, U5.3 (-)
unnamed: C20.1, R21.2, U5.5 (V+)
unnamed: C101.1, R29.2, U101.1 (VDD1)
unnamed: C102.1, R23.2, U101.8 (VDD2)
unnamed: C103.1, R102.2, R104.1, U102.3 (-)
unnamed: C104.1, R105.2, U102.5 (V+)
unnamed: C105.2, C106.1, C107.2, C108.1, C109.2, C110.1, Rbleed1.2, Rbleed2.1
unnamed: C111.2, C112.1, C113.2, C114.1, C115.2, C116.1, Rbleed101.2, Rbleed102.1
unnamed: C117.1, R107.2, R109.1, U103.3 (-)
unnamed: C118.2, U104.6 (BW_SEL)
unnamed: C119.1, R110.2, U103.5 (V+)
unnamed: C120.2, R24.2, U104.8 (VCC)
unnamed: C201.1, R30.2, U201.1 (VDD1)
unnamed: C206.2, R201.2, U203.1 (INA)
unnamed: C207.1, R202.2, U203.2 (INB)
unnamed: C209.2, U202.6 (VZCR)
unnamed: C210.1, R203.2, U203.6 (DT)
unnamed: C211.1, R25.2, U201.8 (VDD2)
unnamed: C212.2, R26.1, U202.8 (VCC)
unnamed: C213.1, R205.2, R208.1, U204.3 (-)
unnamed: C215.1, C218.1, D201.1 (K), U203.16 (VDDA)
unnamed: C217.1, R209.2, U204.5 (V+)
unnamed: C219.1, R217.2, R220.1, U205.3 (-)
unnamed: C220.1, R221.2, U205.5 (V+)
unnamed: D1.2 (A), R7.1
unnamed: D2.2 (A), Q1.1 (G), R10.2, R14.2
unnamed: D3.2 (A), Q2.1 (G), R11.2, R15.2
unnamed: D201.2 (A), R207.1
unnamed: D202.2 (A), Q201.1 (G), R210.2, R214.2
unnamed: D203.2 (A), Q202.1 (G), R211.2, R215.2
unnamed: F101.2, J102.1, J102.2, J102.3, J102.4
unnamed: F102.2, J101.1, J101.2, J101.3, J101.4
unnamed: F103.2, U104.1 (IP+), U104.2 (IP+)
unnamed: L1.1, U2.1 (IP+), U2.2 (IP+)
unnamed: L201.1, U202.1 (IP+), U202.2 (IP+)
unnamed: R4.1, U1.7 (VOUTP)
unnamed: R4.2, R6.2, U4.1 (+)
unnamed: R5.1, U1.6 (VOUTN)
unnamed: R16.2, R18.1, U5.1 (+)
unnamed: R19.2, U6.2
unnamed: R22.2, U6.3
unnamed: R101.1, U101.7 (VOUTP)
unnamed: R101.2, R103.2, U102.1 (+)
unnamed: R102.1, U101.6 (VOUTN)
unnamed: R106.2, R108.1, U103.1 (+)
unnamed: R204.1, U201.7 (VOUTP)
unnamed: R204.2, R206.2, U204.1 (+)
unnamed: R205.1, U201.6 (VOUTN)
unnamed: R216.2, R218.1, U205.1 (+)
unnamed: R219.2, U206.2
unnamed: R222.2, U206.3
VRef: J105.1, R6.1, R206.1

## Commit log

2020-08-27 Added alpha version of Nucleo Shield stage - Routed power board
    Former-commit-id: 01a029c27a9a94b0b38ad9075120ba4737e5d2f9
    [Measurment.kicad_pcb, Power.kicad_pcb, Power.sch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]
2020-08-28 Preliminary routing done - inter layers connectors issues to be solved
    Former-commit-id: 1fb96d105d274f1abe29a0e26bdc8dae707272c3
    [Driver.kicad_pcb, Measurment.kicad_pcb]
2020-08-28 Improved power board traces - Took a power electronic routing guideline into consideration.
    Former-commit-id: b65de051390b66cd68619e9ad7f384f807e5a13c
    [Driver.kicad_pcb, Driver.sch, Measurment.kicad_pcb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]
2020-08-28 Added heatsink holes and bottom mask for the power baord.
    Former-commit-id: e9f6ad10a72fbd59fd7770c8299d44e8e5d9c863
    [Power.kicad_pcb]
2020-08-31 Added optional film caps - Added Heatsink mounting holes Verified mezzanine electrical connexions.
    Former-commit-id: c21533d5300bd1737ccc18ade44e72f7392c108f
    [Driver.kicad_pcb, Measurment.kicad_pcb, Power.kicad_pcb]
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2020-08-31 Added missing values -references - and datasheets to the power schematic.
    Former-commit-id: 1fba3b1af490202e82ca22ba28774caa8dd77ed5
    [Power.sch]
2020-09-01 Improved driver schematic - added missing infos
    Former-commit-id: 2e7d2ee5296ced80b3f6310efa967ae7d5c65057
    [Driver.sch, Power.sch]
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2020-09-01 Addded missing values and datasheet to measurment schematic Minor schematic modifications - added zener diodes
    Former-commit-id: ca748db439ad17fac9869ba7abca15a6fb93549d
    [Driver.kicad_pcb, Measurment.kicad_pcb, Measurment.sch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]
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2020-09-02 Finalized BOM - Added mezzanine connectors overlay - Improved Nucleo shield
    Former-commit-id: fd156602a1b7864c2d9ad92be6606473ba8b7dd5
    [Driver.kicad_pcb, Measurment.kicad_pcb, Power.kicad_pcb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]
2020-09-03 Finalized overlay and added License info and current version Finalized the nucleo shield - added a CR2032 battery holder for the RTC.
    Former-commit-id: a0d3ff1934ccd5b0aac927c38142487f69a56dac
    [Driver.kicad_pcb, Measurment.kicad_pcb, Power.kicad_pcb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]
2020-09-04 Solved minor glitch on the overlay.
    Former-commit-id: 93d94fbb6081fc47753c626b63fa4d0d5fe40414
    [Driver.kicad_pcb, Measurment.kicad_pcb, Power.kicad_pcb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]
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2020-09-07 This branch is a froozen branch containing files up to date at the PCB order time. DO NOT MODIFY.
    Former-commit-id: 0cf30b74249590f722216614308ddaa423907726
    [Driver-B_Cu.gbl, Driver-B_Mask.gbs, Driver-B_SilkS.gbo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]
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2020-10-05 Corrected the interruption routine for AC mode
    Former-commit-id: 1ebb4ea961f3e9fcb3a536778ab39bc6693758c9
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2021-03-10 Revision 1 by Luiz Villa
    Changed some pins, added some test points and validated the overall schematics.
    Former-commit-id: a13ebafad9282ff2edf9e3a2b6cf3a4fc98f8c28
    [Shield_Nucleo.sch]
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2021-03-11 Added missing 3Dfootprints
    Former-commit-id: 8fd08c61bf43df837b41443fbde1082d143220d0
    [Measurment.kicad_pcb, Measurment.sch, Shield_Nucleo.kicad_pcb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]
2021-03-11 Revert "Merge remote-tracking branch 'origin/V1.0_rev_Luiz' into HEAD"
    This reverts commit 30c705c54d182c2fcec0fff7c08cf22eee45f83a [formerly c26ab9cf91983b2456375b9b2c089b126fc558c6], reversing
    changes made to 20a20be3a05677660288fccc9d465dbc21c3f2a2 [formerly 8fd08c61bf43df837b41443fbde1082d143220d0].
    Former-commit-id: abcf50faec7cba1e2dd0cf3d3886566c8097e5d4
    [Shield_Nucleo.sch]
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2021-04-02 WIP: Added power 3D footprint, placed the feeder, the MCU Remapping differential to single ended to be done and ready to route
    Former-commit-id: 88f274329d02ab0ccfd345a516d94f49837cb317
    [Shield_Nucleo.kicad_pcb, Shield_Nucleo.sch]
2021-04-06 WIP: Added pin positions in power footprint Mapped single ended adc on STM32, added feeder filter
    Former-commit-id: 37818e08282c378306756c0cb80776ee704737c1
    [Power.kicad_pcb, Power.sch, Shield_Nucleo.kicad_pcb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]
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2021-04-12 WIP: nearly finished routing - Power need via stiching Signal miss test points connections.
    Former-commit-id: ccb8689d874d573cb7395a7bcd5b7eb16bc98c21
    [Power.kicad_pcb, Power.sch, Shield_Nucleo.kicad_pcb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]
2021-04-15 WIP: First nightly version of V1.1 - Need verification and validation Possible issue with a current loop on the power PCB...
    Former-commit-id: dac9b27b0ef0907937d97832138d9e52bb899697
    [Power.kicad_pcb, Power.sch, Shield_Nucleo.kicad_pcb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]
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2021-04-16 WIP: Corrected small plane mistakes, added GNDREF pin to ext USART and SPI.
    Former-commit-id: 6b7d1d12cdd668c16371049a759145a3d480b167
    [Power.kicad_pcb, Shield_Nucleo.kicad_pcb, Shield_Nucleo.sch]
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2021-05-06 WIP : Added M2 pad holes for EMI shield.
    Former-commit-id: 99336c251299db3618a78f3905645e15bca6cb31
    [Power.kicad_pcb, Power.sch]
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2021-05-21 WIP : Added 3D footprint fuse - more th. vias
    Former-commit-id: 850d5c89ffb75359e2a5d787846585a36f8e7b3b
    [Power.kicad_pcb]
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2021-05-27 Commented the schematic and added missing values
    Former-commit-id: 28a8062f6cb7ce15afe547afbd0adb175197eba9
    [Power.kicad_pcb, Power.sch]
2021-06-01 WIP : Changed HSE from 16Mhz to 24Mhz to match nucleo design.
    Former-commit-id: a67d45cbe7fa1308254aa6a671018fef4ad6e100
    [Shield_Nucleo.sch]
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2021-06-01 Added missing references
    Former-commit-id: fe4b34eaf0e48652d08a4478ced9e9a245668a91
    [Power.sch, Shield_Nucleo.csv, Shield_Nucleo.sch]
2021-06-02 Correct reference U9 ShieldNucleo
    Former-commit-id: 77c6b57a6918131397cc4853bb85803c36835d9a
    [Shield_Nucleo.sch]
2021-06-02 Add ShieldNucleo Bom, Power Bom and Kicost Price for both
    Former-commit-id: 7ec5c6482abdf28c8234ef61f3507741b0dfe68b
    [Kicost_Power.xlsx, Kicost_Shield_Nucleo.xlsx, Power.csv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]
2021-06-10 Add two new folders, Power and ShieldNucleo Definition Package. Add a drill map dimension on Kicad PCB for Power and ShieldNucleo. Change the colour of title block and add new logo on Power and Shiel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
    Former-commit-id: 3f1c15aff2c5620ab849dbbbdfba3198157d15e0
    [Bill_of_materials_Power.ods, Bill_of_materials_Shield_Nucleo.ods, Bom_Power.ods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]
2021-06-17 Creation of the V1.1.2 Branch - Initial commit after repo cleanup
    Former-commit-id: 0b11198abacf3da74430654048e7be3dc8986f68
    [1leg.kicad_pcb, 1leg.sch, Bom_Power.ods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]
2021-06-18 WIP : Closed all issues rised with V1.1.1 prototype.
    Former-commit-id: ef9b1650dc6607c01428260c5066e3e35f8a749d
    [Power.sch, Shield_Nucleo.sch]
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2021-09-23 Added a user comment layer on the control board for interface documentation
    Former-commit-id: 2c17965dcc3eb6ff4a6df14a1920c706aee957bc
    [Shield_Nucleo.kicad_pcb]
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2021-12-16 Added the third power leg. Changed the unductor to 33uH SRP1510. Started a draft of power layout
    Former-commit-id: dc11195cd3fc1550cd7faf78bb21ca53f46a3a45
    [Power.kicad_pcb, Power.sch]
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2022-01-13 Rearranged the schematic for a 3 leg version using subsheets.
    Former-commit-id: 7f090d3ff01c8c46e7948946931d7d731115d26d
    [Power.kicad_pcb, Power.kicad_sch, Power.sch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]
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2022-03-10 Created a first routed STM32G4 module and ordered it in JLCPCB
    Former-commit-id: 49804de64bb80eadc7f05c9bfca13c93680f06aa
    [Feeder-B_Cu.gbl, Feeder-B_Mask.gbs, Feeder-B_Paste.gbp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]
2022-04-05 [Feeder] WIP on the V2 redesign
    Former-commit-id: 5bce92fb9a428cd005e74b891f189b6460f88472
    [Feeder.kicad_pcb, Feeder.kicad_sch, microcontroller_mini.kicad_pcb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]
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2022-04-19 [Power] Finished routing all the tracks, no more rastnet, ready for refining
    Former-commit-id: c85419efed005dbd6b325ef0aef7156952f8cebe
    [Power.kicad_pcb, PowerLeg1.kicad_sch]
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2022-06-08 WIP: mooving to a single board implementation with 160x100 form factor.
    Former-commit-id: e8c19d5fc5237412fb5a003591d44756dbc6e173
    [Feeder.kicad_pcb, Feeder.kicad_sch, Microcontroller.kicad_pcb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]
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2022-06-10 WIP : 99 percents of the nets are now routed properly
    Former-commit-id: fcbb95e3f0a6512a63faba729c3990d7109d7768
    [Feeder.kicad_sch, Microcontroller.kicad_sch, Power.kicad_sch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]
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2022-06-14 WIP : Started correcting MCU board mistakes
    Former-commit-id: 0e34b6d72e10d1eac13c8cf31fc8e8f14d7f468b
    [Feeder.kicad_sch, Microcontroller.kicad_sch, Power.kicad_sch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]
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2022-07-06 WIP : Finalized the rework of the MCU board. Added extra pins to be able to interact with all the native pinout of the G474 Choosen to deploy the bootloader pin on PC14, it will require a custom boot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
    Former-commit-id: c1ded6b4e2272d08c1bdd5e172bcf8412ac79a26
    [microcontroller_mini.kicad_pcb, microcontroller_mini.kicad_sch]
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

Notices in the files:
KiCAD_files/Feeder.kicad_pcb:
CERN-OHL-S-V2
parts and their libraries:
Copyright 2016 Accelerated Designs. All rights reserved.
